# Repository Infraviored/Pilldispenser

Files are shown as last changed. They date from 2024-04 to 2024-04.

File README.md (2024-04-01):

# Smart Pill Dispenser Project

The Smart Pill Dispenser is an automated system designed to reliably dispense supplements or medication at scheduled intervals. This project combines hardware ingenuity with software integration to provide a seamless and efficient solution for managing daily health routines. It's perfect for integration into smart home systems like Home Assistant, offering both convenience and reliability.

## Overview

The Smart Pill Dispenser is an innovative solution designed to automate the process of dispensing pills, making it an essential tool for individuals managing supplements or medications. Utilizing a servo-controlled rotating disc, this system precisely dispenses pills from individual reservoirs into a collection cup. It is equipped with a robust web interface for easy scheduling and control, using MQTT commands for seamless integration into existing smart home setups like Home Assistant. This README provides a detailed guide on the hardware components, software setup, and usage instructions to get your Smart Pill Dispenser operational.

<div style="display:flex; justify-content:space-between; align-items:center;">
  Front View of Pill Dispenser
  Rotating Discs
</div>

## Hardware

### Electrical Components
- **SG 90 Servo Motor:** Controls the rotating disc for dispensing pills.
- **Feedback Lights:** Provides visual feedback for successful dispensing and error notifications.
- **D1 Mini Microcontroller:** A Wemos D1 mini programmed with PIO (PlatformIO) code provided in the repository.
- **Piezo:** A cheap circular Piezo with less than 40mm diameter is required as impact drop sensor. Any will do.
- **Feedback Lights (Optional):** Provide visual feedback for successful dispensing and error notifications.
  
### Plastic Components

- **Pill Reservoirs:** Individual containers for each type of pill.
- **Rotating Disc:** Features a hole to grab and release pills into the collection cup.
- **Collection Cup:** Located at the bottom of the machine where dispensed pills are collected.

### Assembly

1. **3D Printed Parts:** Utilize the provided CAD models (`F3D` and `STEP` files) to print the physical components of the dispenser.
2. **Servo Motor Installation:** Fit the servo motor to the rotating disc ensuring it aligns correctly with the pill reservoirs.
3. **Final Assembly:** Follow the detailed assembly guide in the `hardware` folder to put together all parts of the pill dispenser.

## Features and Functionality

- **Automated Pill Dispensing:** Schedule daily dispensing at fixed intervals without manual intervention.
- **Smart Home Integration:** Easily integrates with existing smart home systems like Home Assistant via MQTT.
- **Error Handling:** Automated alerts for unsuccessful dispensing attempts, likely due to empty tanks.
- **Visual Feedback:** Light indicators for successful dispensing and error notifications ensure you're always informed.

## Support

For support, questions, or feedback, please open an issue in the GitHub repository or contact the maintainers directly.

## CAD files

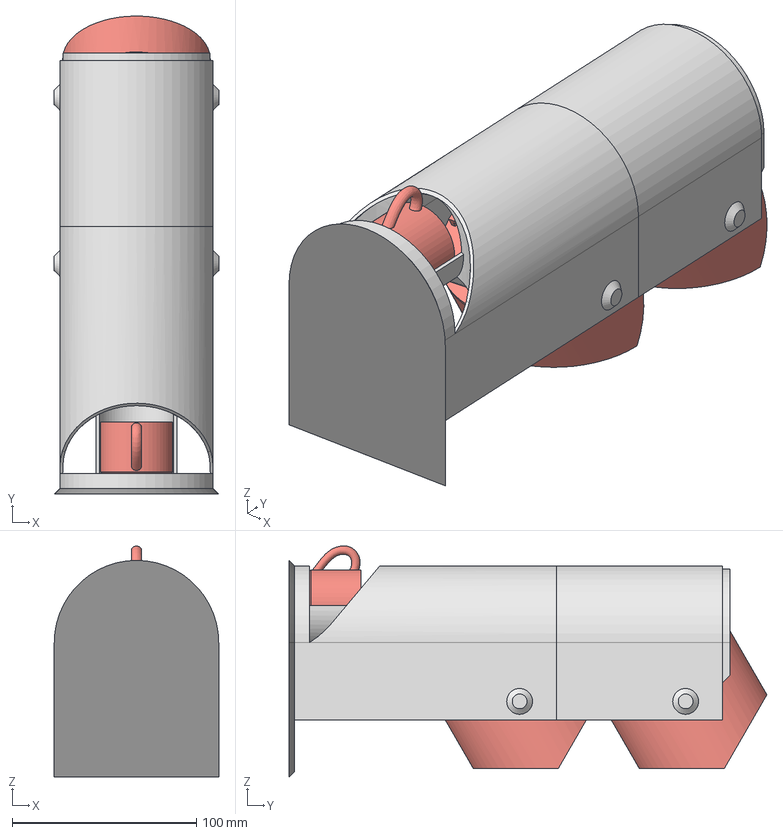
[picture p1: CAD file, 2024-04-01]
CAD/PillDispenser.step
89.2 x 259.1 x 125.2 mm
Schale x 2
Base
Motortraeger x 2
Tasse (1)
Servo x 2
Scheibe_Omega3
Scheibe_Zink
Base 2
Tassenunterlage
Bodenplatte

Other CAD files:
CAD/PillDispenser.f3d

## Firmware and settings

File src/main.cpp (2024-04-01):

#include <Arduino.h>
#include <Servo.h>
#include <ESP8266WiFi.h>
#include <PubSubClient.h>
#include "config.h"
#include "connection.h"
#include "Breather.h"
// Function prototypes
void dispense(int *servo);
void shakeBottom(int *servo);
void moveTo(int *servo, int position, int duration);
void handleMqttMessage(char* topic, byte* payload, unsigned int length);
void detect_collection(); 
int step_value = 0;
int collection_value = 0;

bool uncollected = false;
int detectionCount = 0;
unsigned long firstDetectionTime = 0;
unsigned long secondDetectionTime = 0;

// Declare a global servo object
Servo currentServo;

#define RED_LED_PIN 4
#define WHITE_LED_PIN 5

Breather redBreather(RED_LED_PIN);
Breather whiteBreather(WHITE_LED_PIN);

void start_breathing(Breather &breather1, int cycleDuration1, Breather *breather2 = nullptr, int cycleDuration2 = 0, unsigned long offset2 = 0)
{
  breather1.startBreathing(cycleDuration1);
  if (breather2)
  {
    delay(offset2);
    breather2->startBreathing(cycleDuration2);
  }
}

void breathe_once(Breather &breather1, int cycleDuration1, unsigned long startDelay1 = 0, Breather *breather2 = nullptr, int cycleDuration2 = 0, unsigned long startDelay2 = 0)
{
  breather1.breatheOnce(cycleDuration1, startDelay1);

  if (breather2)
  {
    breather2->breatheOnce(cycleDuration2, startDelay2);
  }

  unsigned long endTime = millis() + cycleDuration1 + startDelay1;
  if (breather2)
  {
    unsigned long breather2EndTime = millis() + cycleDuration2 + startDelay2;
    if (breather2EndTime > endTime)
    {
      endTime = breather2EndTime;
    }
  }

  while (millis() < endTime)
  {
    breather1.update();
    if (breather2)
      breather2->update();
    delay(10); // Small delay to avoid CPU hogging
  }
}

void setup()
{
  Serial.begin(115200);
  Serial.println("Starting up...");

  pinMode(SENSOR_PIN, INPUT);


  redBreather.initialize();
  whiteBreather.initialize();

  breathe_once(redBreather, 1000, 0, &whiteBreather, 1000, 500);
  client.setServer(mqtt_server, mqtt_port);
  client.setCallback(handleMqttMessage);

  setup_wifi();
  reconnect();



  Serial.println("Ready to give drugs!");
  breathe_once(redBreather, 2100, 0, &whiteBreather, 2100, 1000);
}


void loop()
{
  if (!client.connected())
  {
    reconnect();
  }
  redBreather.update();
  whiteBreather.update();
  client.loop();
  if (uncollected) {
    detect_collection();
  }
  delay(20);
}

void handleMqttMessage(char *topic, byte *payload, unsigned int length)
{
  Serial.println("Command received");
  String message = "";
  for (unsigned int i = 0; i < length; i++)
  {
    message += (char)payload[i];
  }

  // Use the global constant for topic comparison
  if (strcmp(topic, commandTopic) == 0)
  {
    if (message == "dispense_zinc")
    {
      Serial.println("Dispense zinc");
      client.publish(stateTopic, "dispensing Zinc");
      dispense(zinc);
    }
    else if (message == "dispense_omega")
    {
      client.publish(stateTopic, "dispensing Omega");
      Serial.println("Dispense omega");
      dispense(omega);
    }
    else if (message == "dispense_magnesium")
    {
      client.publish(stateTopic, "dispensing Magnesium");
      Serial.println("Dispense magnesium");
      dispense(magnesium);
    }
    else if (message == "reset_error")
    {
      Serial.println("Reset the red blinker");
      redBreather.stopBreathing();
      client.publish(stateTopic, "ready");
    }
    else
    {
      Serial.println("Command unknown");
    }
  }
}

void moveTo(int *servo, int position, int duration){
  int oldPosition = servo[4];
  int deltaPos = abs(oldPosition - position);
  currentServo.attach(servo[0], lowestPWM, highestPWM);

  if (duration == 0 || deltaPos*maxRate > duration){ //no duration given or duration smaller than minimal Time

  currentServo.write(position);
  delay(maxRate*deltaPos);
  }

  else {
    if (oldPosition <= position){
      for (int pos = oldPosition; pos <= position; pos += 1) {
        currentServo.write(pos);
        delay(duration/deltaPos);
      }

    } else{
      for (int pos = oldPosition; pos >= position; pos -= 1) {
        currentServo.write(pos);
        delay(duration/deltaPos);
      }
    }
  }
  currentServo.detach();
  servo[4] = position;
}



void shakeBottom(int *servo){
  int lowpos = servo[1];
  int highpos = lowpos - servo[5];
  for (int j = 0; j < 8; j++) {
    moveTo(servo, lowpos, 0);
    moveTo(servo, highpos, 0);
  }
}

void detect_collection()
{
  step_value = analogRead(SENSOR_PIN);
  if (step_value < 14)
  {
    step_value = 0;
  }
  collection_value = 10 * step_value + collection_threshold_factor * collection_value;
  Serial.println(collection_value);
  if(collection_value > collection_threshold)
  {
    Serial.println("Collection detected");
    client.publish("pilldispenser/state", "ready");
    uncollected = false;
    collection_value = 0;
    redBreather.stopBreathing();
    whiteBreather.stopBreathing();
  }
}

bool dropSense(int *servo) {
  //pre drop location is LARGER
  int preDropLocation = servo[2];
  int dropLocation = servo[3];
  int duration = servo[6];

  // Move to pre drop location
  moveTo(servo, preDropLocation, 800);

  // Attach servo
  currentServo.attach(servo[0], lowestPWM, highestPWM);

  // Calculate distance to drop location
  float deltaPos = abs(preDropLocation - dropLocation);

  bool dropped = false;

  // First loop: Read and move for 1/2 second
  for (int i = 0; i < 20; i++) {
    // Read sensor value and move servo
    int sensorValue = analogRead(SENSOR_PIN);
    Serial.println(sensorValue);
    int pos = preDropLocation - deltaPos * ((float)i / (float)20);
    currentServo.write(pos);

    // Check if threshold is reached
    if (sensorValue > drop_threshold) {
      Serial.println("DROP");
      dropped = true;
      break;
    }
  }

  // Second loop: Read only, Skip when already dropped.
  if (!dropped) {
    for (int i = 0; i <= (duration*2); i++) {
      int sensorValue = analogRead(SENSOR_PIN);
      Serial.println(sensorValue);

      // Check if threshold is reached
      if (sensorValue > drop_threshold) {
        Serial.println("DROP");
        dropped = true;
        break;
      }
    }
  }

  // Detach servo and return result
  currentServo.detach();
  if (dropped) {
    return true;
  } else {
    Serial.println('-');
    return false;
  }
}

  void dispense(int *servo)
  {
        for (int i = 0; i < 5; i++)
    {
      moveTo(servo, servo[1], 0);
      shakeBottom(servo);

      if (dropSense(servo))
      {
        Serial.println("Dispensed!");
        uncollected = true;
        start_breathing(redBreather, 4000, &whiteBreather, 2000, 1000);
        client.publish("pilldispenser/state", "Pills ready");
        delay(100);
        return;
      }
      client.loop();
    }
    Serial.println("Error: Pill dispenser empty!");
    client.publish("pilldispenser/state", "Dispense Error");
    redBreather.startBreathing(200);
  }

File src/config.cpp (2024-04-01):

#include "config.h"
#include <ESP8266WiFi.h>

//! IMPORTANT! RENAME!
const char *MQTT_DEVICE_NAME = "pilldispenser";

// Construct topics using String and then convert back to const char*
String sCommandTopic = String(MQTT_DEVICE_NAME) + "/commands";
String sStateTopic = String(MQTT_DEVICE_NAME) + "/state";
const char *commandTopic = sCommandTopic.c_str();
const char *stateTopic = sStateTopic.c_str();

// Pin to which the sensor is connected
const int SENSOR_PIN = A0;
const int RED_LED_PIN = D2;
const int WHITE_LED_PIN = D1;

// Threshold value for triggering the sensor
const int drop_threshold = 20;
const int collection_threshold = 1200;
const float collection_threshold_factor = 0.93;

const int lowestPWM = 415;
const int highestPWM = 2575;

const int rotationBeforeDrop = 15;

const int maxRate = 3;




// DISPENSER DEFINITIONS

//                   PIN         LOWEST      PREDROP     DROP        LASTPOS     SHAKEDIST   FALLDURATION
int zinc[] =        {D5,         180,        30,         2,          0,          22,         2400};
int omega[] =       {D6,         180,        40,         0,          0,          30,         1600};
int magnesium[] =   {D7,         180,        30,         12,         0,          30,         1200};

// PIN: Where the Servo PWM Pin is connected.
// LOWEST: Lowest Position  of the disk in degrees. 180 normally is the lowest Point, 0 is the highest.
// PREDROP: The Location to where the hole of the disk moves before the dropping sequence (with detection) is started. This should be chosen s.t. the Pill is just before the hole but can not fall out yet.
// DROP: The Loctaion where the drop happens. This is normally close to 0 degrees (the uppermost position).
// SHAKEDIST: from the LOWEST Point, how far up the disk should be moved during one shaking motion.
// DURATION: How long the dropping sequence with detection should take. The further up the Dispenser is, the longer the time it takes to fall down, the more DURATION is needed.




int order[] = {*zinc, *omega, *magnesium};
